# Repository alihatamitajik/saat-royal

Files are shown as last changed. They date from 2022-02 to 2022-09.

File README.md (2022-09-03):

<!-- Improved compatibility of back to top link: See: https://github.com/othneildrew/Best-README-Template/pull/73 -->

<!--
*** Thanks for checking out the Best-README-Template. If you have a suggestion
*** that would make this better, please fork the repo and create a pull request
*** or simply open an issue with the tag "enhancement".
*** Don't forget to give the project a star!
*** Thanks again! Now go create something AMAZING! :D
-->

<!-- PROJECT SHIELDS -->
<!--
*** I'm using markdown "reference style" links for readability.
*** Reference links are enclosed in brackets [ ] instead of parentheses ( ).
*** See the bottom of this document for the declaration of the reference variables
*** for contributors-url, forks-url, etc. This is an optional, concise syntax you may use.
*** https://www.markdownguide.org/basic-syntax/#reference-style-links
-->
[][contributors-url]
[][forks-url]
[][stars-url]
[][issues-url]
[][license-url]
[][linkedin-url]

<!-- PROJECT LOGO -->
<br />
<div align="center">
  <a href="https://github.com/alihatamitajik/saat-royal">
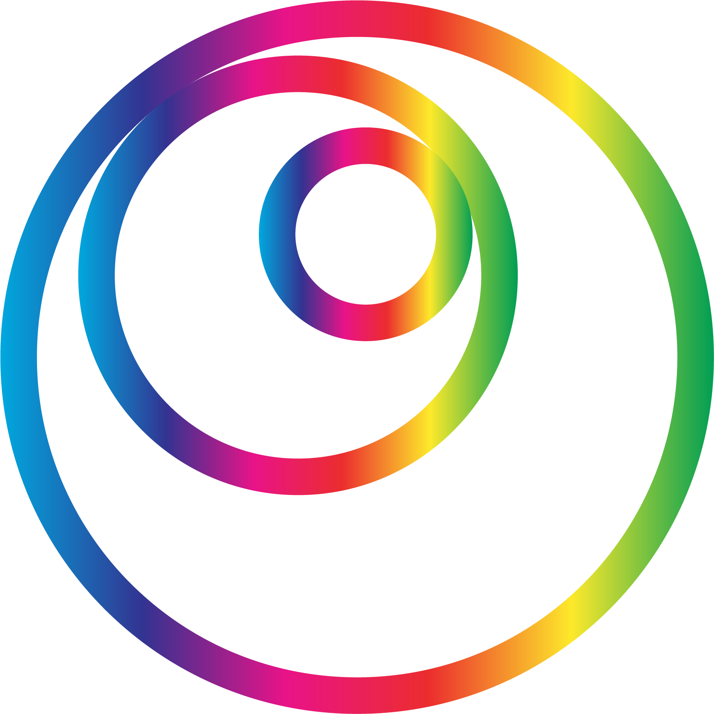
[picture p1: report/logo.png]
    
  </a>

<h3 align="center">Sa@RoyAl</h3>

  <p align="center">
    NodeMCU-based Analog-alike RGB Clock with Android Controller
    <br />
    <a href="https://github.com/alihatamitajik/saat-royal"><strong>Explore the docs »</strong></a>
    <br />
    <br />
    <a href="https://github.com/alihatamitajik/saat-royal">View Demo</a>
    ·
    <a href="https://github.com/alihatamitajik/saat-royal/issues">Report Bug</a>
    ·
    <a href="https://github.com/alihatamitajik/saat-royal/issues">Request Feature</a>
  </p>
</div>

<!-- TABLE OF CONTENTS -->
<details>
  <summary>Table of Contents</summary>
  <ol>
    <li>
      <a href="#about-the-project">About The Project</a>
      <ul>
        <li><a href="#built-with">Built With</a></li>
      </ul>
    </li>
    <li>
      <a href="#getting-started">Getting Started</a>
      <ul>
        <li><a href="#prerequisites">Prerequisites</a></li>
        <li><a href="#installation">Installation</a></li>
      </ul>
    </li>
    <li><a href="#roadmap">Roadmap</a></li>
    <li><a href="#contributing">Contributing</a></li>
    <li><a href="#license">License</a></li>
    <li><a href="#contact">Contact</a></li>
  </ol>
</details>

<!-- ABOUT THE PROJECT -->
## About The Project

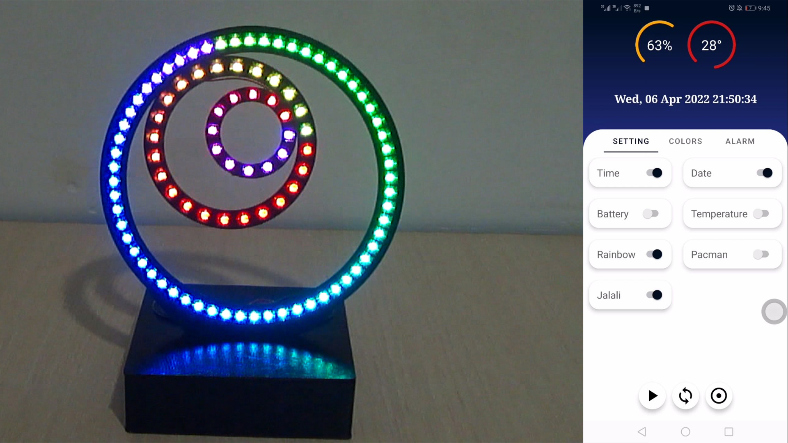
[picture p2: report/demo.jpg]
Product Name Screen Shot


This project is based on development board NodeMCU-8266 and WS2812B RGB LEDs. There are 60, 24 and 12 pieces rings in the
clock face that will represent different information and the clock settings is controlled by REST API (An android app is created
for better control). NodeMCU is on AccessPoint mode and devices must connect to its network first before they can change its
settings. 

Inspired by [This Project](https://www.instructables.com/Neopixel-Clock-With-Three-Neopixel-Rings)

Features:
* Time (Obviously! **3** Different Mode)
* Date (Jalali & Gregorian)
* Battery Percentage
* Temperature of the Room
* Two Beauty Mode (PacMan ᗤ and Rainbow 🌈)
* Alarm (Mario Theme Song)
* Customizable Colors
* REST API

<p align="right">(<a href="#readme-top">back to top</a>)</p>

### Built With

* [][Arduino-url]
* [][Android-url]
* [][VSC-url]

<p align="right">(<a href="#readme-top">back to top</a>)</p>

<!-- GETTING STARTED -->
## Getting Started

These parts is used:
* NodeMCU ESP8266 CP2102
* NeoPixel Ring - X60/X24/X12 5050 RGB LED WS2812B
* DS1307 - RTC
* Voltage Sensor
* 0.5 Watt 8 Ohm Speaker
* LM386 Mini Amplifier
* Voice Sensor FC-04
* DS18B20 - Temperature Sensor
* Printed watch face and body
* Mini Breadboard
* Jumper Wires
* 18650 Battery Shield V3 + 18650 Battery

### Prerequisites

Connect the parts to the board. Change the `#define`s relatively.

Libraries:
* ESP8266 (Board should be added to Arduino IDE ([help](https://randomnerdtutorials.com/how-to-install-esp8266-board-arduino-ide/)))
* RTClib (With this exact title)
* [ESPAsync](https://reacoda.gitbook.io/molemi-iot/introducing-the-nodemcu/display-the-dht11-sensor-reading-on-a-web-server-using-nodemcu./installing-dht-library-on-the-esp8266/i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) 
* Adafruit NeoPixel
* DallasTemperature
* OneWire

### Installation

The main program of the board can be found [HERE](code). Program the board and Enjoy! 

<p align="right">(<a href="#readme-top">back to top</a>)</p>

## RoadMap

- [ ] Adding TF card that will play a custom sound
  - [ ] TF card wiring
  - [ ] Sound transfer API

<!-- CONTRIBUTING -->
## Contributing

Contributions are what make the open source community such an amazing place to learn, inspire, and create. Any contributions you make are **greatly appreciated**.

If you have a suggestion that would make this better, please fork the repo and create a pull request. You can also simply open an issue with the tag "enhancement".
Don't forget to give the project a star! Thanks again!

1. Fork the Project
2. Create your Feature Branch (`git checkout -b feature/AmazingFeature`)
3. Commit your Changes (`git commit -m 'Add some AmazingFeature'`)
4. Push to the Branch (`git push origin feature/AmazingFeature`)
5. Open a Pull Request

<p align="right">(<a href="#readme-top">back to top</a>)</p>

<!-- LICENSE -->
## License

Distributed under the MIT License. See `LICENSE.txt` for more information.

<p align="right">(<a href="#readme-top">back to top</a>)</p>

<!-- CONTACT -->
## Contact

Your Name - [@alihatamitajik](https://twitter.com/alihatamitajik) - a [DOT] hatam008 [AT] gmail [DOT] com

Project Link: [https://github.com/alihatamitajik/saat-royal](https://github.com/alihatamitajik/saat-royal)

<p align="right">(<a href="#readme-top">back to top</a>)</p>

<!-- MARKDOWN LINKS & IMAGES -->
<!-- https://www.markdownguide.org/basic-syntax/#reference-style-links -->
[contributors-shield]: https://img.shields.io/github/contributors/alihatamitajik/saat-royal.svg?style=for-the-badge
[contributors-url]: https://github.com/alihatamitajik/saat-royal/graphs/contributors
[forks-shield]: https://img.shields.io/github/forks/alihatamitajik/saat-royal.svg?style=for-the-badge
[forks-url]: https://github.com/alihatamitajik/saat-royal/network/members
[stars-shield]: https://img.shields.io/github/stars/alihatamitajik/saat-royal.svg?style=for-the-badge
[stars-url]: https://github.com/alihatamitajik/saat-royal/stargazers
[issues-shield]: https://img.shields.io/github/issues/alihatamitajik/saat-royal.svg?style=for-the-badge
[issues-url]: https://github.com/alihatamitajik/saat-royal/issues
[license-shield]: https://img.shields.io/github/license/alihatamitajik/saat-royal.svg?style=for-the-badge
[license-url]: https://github.com/alihatamitajik/saat-royal/blob/master/LICENSE
[linkedin-shield]: https://img.shields.io/badge/-LinkedIn-black.svg?style=for-the-badge&logo=linkedin&colorB=555
[linkedin-url]: https://linkedin.com/in/ali-hatami-tajik/
[product-screenshot]: report/demo.jpg
[Arduino]: https://img.shields.io/badge/%20-Arduino-00979D?style=for-the-badge&logo=Arduino&logoColor=fff
[Arduino-url]: https://Arduino.cc
[VSC]: https://img.shields.io/badge/%20-VS%20Code-007ACC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
[VSC-url]: https://code.visualstudio.com/
[Android]: https://img.shields.io/badge/%20-Android-3DDC84?style=for-the-badge&logo=Android&logoColor=fff
[Android-url]: https://www.android.com/

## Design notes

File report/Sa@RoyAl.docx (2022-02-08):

به نام خدا

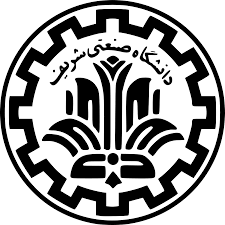
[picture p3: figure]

ساعت دیجیتال عقربه ای

پروژه درس سیستم های نهفته
جناب آقای دکتر انصاری

سارا آذرنوش 98170668

علی حاتمی 98101385

رویا قوامی 98171031

زمستان ۱۴۰۰

## مقدمه

در این پروژه یک ساعت عقربه ای با استفاده از امکانات دیجیتال بصورتی که تمام بخش های این ساعت (عقربه ها و محیط دایره ساعت) از 3 حلقه ی LED RGB ساخته شده است و با استفاده از یک اپلیکیشن موبایل میتوان بصورت بی سیم رنگ و همچنین تنظیمات زمان ساعت این ساعت را تغییر داد.

## طرح ساعت

طراحی مد نظر به این صورت است که نمایش زمان با استفاده از سه حلقه از LED های RGB با اندازه‌های ۶۰، ۲۴ و ۱۲ صورت خواهد گرفت. این حلقه ها بر روی یک پایه که حاوی ماژول های مورد نیاز ساعت است قرار میگیرد.

شکل صفحه ساعت (Watch Face) به صورت زیر است:

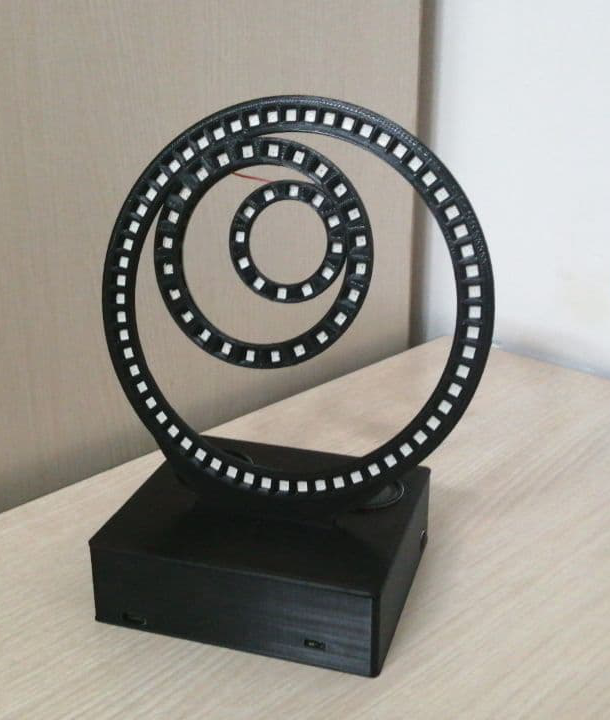
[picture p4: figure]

## لوازم مورد نیاز

لوازم مورد نیاز با توجه به ناحیه مصرف آنها عبارت‌اند از:

- پردازشی:

Cp2102 با چیپ EPS8266 بر پایه‌ی NodeMCU

- روشنایی:

برای روشنایی این ساعت از led های WS2812B پکیج 5050 استفاده خواهد شد. پیشتر استفاده از این تکنولوژی برای کنترل کردن led ها به خصوص در تعداد بالا شبیه به یک کابوس بود اما با استفاده از این led های آدرس پذیر با اتصال آنها به صورت daisy chain و تنها با استفاده از یک خط داده میتوان آنها را کنترل کرد. برای این ساعت از ۹۶ عدد از آنها به شرح زیر استفاده خواهد شد:

  - NeoPixel Ring - X60 5050 RGB LED WS2812B
  - NeoPixel Ring - X24 5050 RGB LED WS2812B
  - NeoPixel Ring - X12 5050 RGB LED WS2812B
- ساعت:

Real-time Clock DS1307 with I2C Interface

- توان این ساعت از ۹۶ چراغ LED WS2812B تشکیل شده است که در حالتی که خاموش باشند ۱ میلی آمپر و در حالت روشنایی ۶۰ میلی آمپر مصرف دارند. برای کنترل مصرف این ساعت از این تکنیک (به پیشنهاد مهندس سیادت‌زاده) استفاده خواهد شد که ساعت همیشه روشن نخواهد بود و تنها در رویدادهای خاصی (مثل دریافت صدای کف‌زدن یا بر اساس یک تایمر خاص) زمان را نشان خواهد داد. برای توان بخشی از مدار از ملزومات زیر استفاده خواهد شد:

2200 - 18650 ‌Battery Shield V3:

این شیلد دارای یک، دو یا چهار باطری است که خروجی ثابت ۵ ولت و ۳ ولت به ما تحویل می‌دهد و برای روشن کردن چراغ‌ها و میکروکنترلر استفاده میشود. این شیلد کار تنظیم و مصرف توان را بسیار ساده می‌کند.

Voltage Sensor:

از یک سنسور ولتاژ برای گرفتن ولتاژ خام دو سر باتری استفاده می‌شود تا با توجه به ولتاژ آن بتوان میزان باطری باقی‌مانده درون آن را خواند و با توجه به منحنی شارژ دهی-میزان شارژ باقی‌مانده شارژ باطری را نمایش داد. البته شیلد باطری خود این کار را می کند اما چون می‌خواهیم این اطلاعات از طریق نرم‌افزار قابل دسترسی باشند به این سنسور نیاز خواهیم داشت.

- صوت: در بخش اختیاری است و می‌توان صوت‌های دلخواه را روی یک میکرو sd ریخت یا اینکه برای درایو بهتر اسپیکر از یک آمپلیفایر استفاده کرد. اما می‌توان تنها به اسپیکر اکتفا کرد و با استفاده از تن‌ها، موسیقی‌های ابتدایی برای زنگ و دیگر کارکرد‌ها ساخت.
  - 0.5 Watt 8 Ohm Speaker
  - (Optional) LM386 Mini Amplifier
  - (Optional) Micro SD Card Module
- سنسورها:
  - Voice Sensor FC-04
  - TTP223 Touch Sensor
  - DS18B20 Temperature Sensor
- ملزومات ساخت:
  - Printed watch face and body
  - Mini Breadboard
  - Jumper Wires
  - Soldering iron + ...

## قابلیت‌ها

- نمایش ساعت (با چند نحوه نمایش متفاوت)
- دارای mode هایی برای استفاده به عنوان چراغ خواب یا تزئین
- قابلیت کنترل و تغییر برنامه و اطلاع از وضعیت فعلی توسط اپلیکیشن موبایل
- هشدار (آلارم)
- حالات متفاوت رنگ
- نمایش تاریخ
- نمایش دما

## مراحل کار

### نوشتن پروپوزال:

نیازمندی‌ها و هدف از انجام پروژه را مشخص کرده و به صورت کتبی در می‌آوریم.

اسلاید (https://docs.google.com/presentation/d/1GC8DirnFEurxau7_LiZFlntKh-j90mExHD0EmSQnUcM/edit) تهیه شده و پروپوزال گیت هاب (https://github.com/Sharif-Embedded-system/final_project-azarnoosh-hatamitajik-ghavami/tree/main/proposal) در این لینک‌‌ها موجود هستند.

### تهیه قطعات مورد نیاز:

در ابتدا با توجه به نیازمندی های پروژه، قطعات مورد نیاز گفته شده را تهیه میکنیم.

### ساخت قالب موردنظر:

برای ساخت به قالب فیزیکی ساعت به دو بخش زیر نیاز داریم.

ساعت:

سه حلقه 60، 24 و 12 عددی که به ترتیب اندازه به شکل مماس در شمال غربی حلقه 60 عددی قرار میگرند و ابعاد آن متناسب با رشته LED تهیه شده است.

پایه:

یک مکعب مستطیل خالی که ماژول های مورد نیاز گفته شده در داخل آن قرار میگیرند و ساعت روی آن قرار میگرد.

نتیجه نهایی در گیت هاب (https://github.com/Sharif-Embedded-system/final_project-azarnoosh-hatamitajik-ghavami/tree/main/report/3d-model) موجود است.

### ساخت فیزیکی و انجام اتصال فیزیکی:

ریسه‌های LEDرا در حلقه مورد نظر قرار داده و میچسبانیم سپس آن ها را به صورت سریالی به یکدیگر لحیم میکنیم. ماژول های داخل نیز که شامل باتری و سنسور ولتاژ متصل به آن، ماژول ساعت و صدا هستند را همگی را به بلوتوث متصل میکنیم.

### نوشتن برنامه‌ی سخت افزار:

برای نوشتن کدهای سخت افزاری از Arduino و زبان c++ استفاده شده است.

* کار با میکروفون(MIC):

شکل ظاهری سخت افزار:

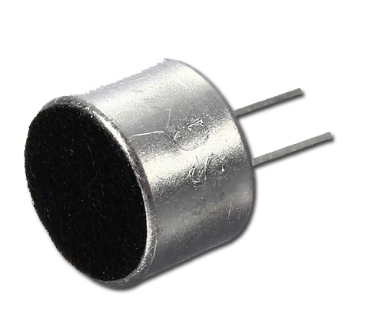
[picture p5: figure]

تابع checkTrigger: این تابع برای کار با میکروفون است که دو flag دریافت می کند و داخل loop صدا می شود و دارای دو state است:

1. "دست زدن اول" (first clap) شناسایی یا capture نشده باشد .

2. "دست زدن اول" شناسایی شده باشد و منتظر "دست زدن دوم" می ماند و اگر رخ نداد، اولی را نیز حذف می کند.

درواقع بعد از گذشتن زمانی ما بین ۳۵۰ تا ۱۳۰۰ میلی ثانیه اگر "دست زدن دوم" تشخیص داده شد، به عنوان double clap درنظر گرفته می شود و در غیر این صورت، "دست زدن اول" ی حذف می شود و دوباره مراحل داخل لوپ تکرار میشوند.

- کار با اسپیکر:

در این پروژه با اتصال یک اسپیکر به پین (pin) یازدهم (می توان پین جدید انتخاب کرد) میتوان آهنگ Super Mario Bros - Overworld theme را پخش کرد. فایل مربوطه به کدهای این قسمت در این لینک (https://github.com/Sharif-Embedded-system/final_project-azarnoosh-hatamitajik-ghavami/blob/main/code/SaRoyAl/Melody.ino) قابل مشاهده است.

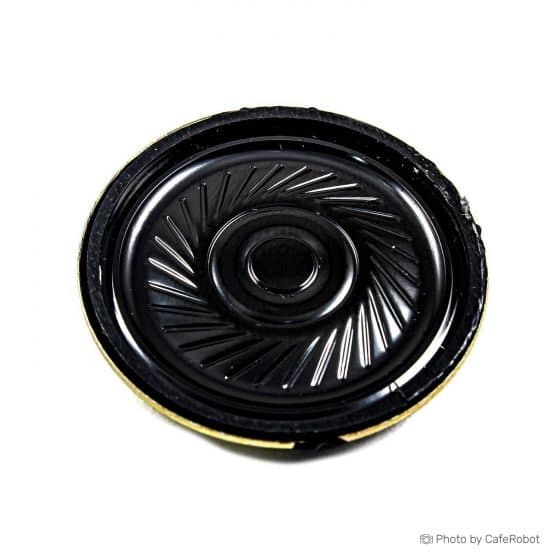
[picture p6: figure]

در این پروژه با اتصال یک زنگ پیزو به پین (pin) یازدهم (می توان پین جدید انتخاب کرد) میتوان آهنگ Super Mario Bros - Overworld theme را پخش کرد. فایل مربوطه به کدهای این قسمت در این لینک (https://github.com/Sharif-Embedded-system/final_project-azarnoosh-hatamitajik-ghavami/blob/main/code/SaRoyAl/Melody.ino) قابل مشاهده است.

کار با LED های ساعت و مودهای مختلف آن:

در این بخش، برای کنترل پیکسل ها و نوارهای LED مبتنی بر تک-سیم (single wire) از کتابخانه آردوینو (Ardunio library) استفاده شده است. این کتابخانه با تمام معماری ها سازگار بوده و بنابراین می توان از آن در تمام بردهای آردوینو استفاده کرد.

در این معماری، از سه حلقه LED با اندازه های ۶۰، ۲۴ و ۱۲ استفاده شده است و در نتیجه برای مپ کردن عدد پیکسل گفته شده به هر یک، map60، map24 و map12 را تعریف می کنیم.

ساعت دارای سه استیت کلی FF_MODE، SWING_MODE و SIMPLE_MODE برای نمایش زمان می باشد. در فایل کدهای مربوط به این قسمت (RGB.ino) به کمک توابع تعریف شده در کتابخوانه آردوینو، مانند setPixelColor و مپ های تعریف شده که بالا به آن اشاره کردیم، بعد از گرفتن زمان حال حاضر و استفاده از لیست colorScheme که در آن ۱۲ رنگ تعریف کردیم، mode های مختلف ساعت را می توان با روشن و خاموش کردن پیکسل ها نمایش داد.

- کار با RTC (Real Time Clock):

برای کار با RTC از کتابخانه RTClib استفاده می کنیم. این کتابخانه به آردوینو اجازه می دهد تا RTC داخلی (Real Time Clock) را کنترل و استفاده کند. ساعت بلادرنگ ساعتی است که زمان حال حاضر را ردیابی می کند و می توان از آن برای برنامه ریزی اقدامات برنامه در یک زمان خاص استفاده کرد.

به علاوه، RTC می تواند در هر حالت sleep mode به کار خود ادامه دهد، بنابراین، می توان از آن برای اصطلاحا "بیدار کردن " دستگاه از حالت های خواب استفاده کرد. هر بار که برد روشن می شود، RTC ریست می شود و از یک تاریخ استاندارد شروع به کار می کند.

در فایل مربوط به این قسمت (RTC.ino)، تابعی برای تشخیص آلارم (isAlarm)، تابعی برای به روزرسانی زمان (به کمک تابع rtc.now())، تابعی برای ست کردن RTC به تاریخ و زمان صریح به صورت زیر و در نهایت نیز تابع initializer آن قرار دارند.

January 21, 2014 at 3am rtc.adjust(DateTime(2014, 1, 21, 3, 0, 0))

- کار با سنسور دما:

کد مربوط به این قسمت در Temprature.ino قرار دارد. برای کار با سنسور دما، از کتابخانه های DallasTemperature.h و OneWire استفاده می کنیم. ابتدا یک instance از OneWire ساخته تا بتوان با هر وسیله ای که با یک wire می تواند وصل شود ارتباط برقرار کرد و سپس آن را به کتابخانه DallasTemperature.h می دهیم. در نهایت، به کمک تابع getTemprature، دمای محیط را به سیلسیوس بر میگردانیم.

ارتباط با اپ موبایل:

در فایل SaRoyAl.ino، کد بدنه ساعت دیجیتال قرار دارد که به توضیح آن می پردازیم:

· ریکوست هایی که می توان به ساعت فرستاد:

/ : برای تست ارتباط مناسب

status/: پاسخ این ریکواست، درصد باتری، دمای محیط و زمان فعلی است.

adjust/: با فرستادن این ریکواست، ساعت دیجیتال با ساعت محلی موبایل تنظیم می شود.

alarm/: با فرستادن این ریکواست، تنظیمات آلارم برای موبایل فرستاده می شود.

setting/: با فرستادن این ریکواست، تنظیمات استیت ها برای موبایل فرستاده می شوند.

colors/: با فرستادن این ریکواست، تنظیمات رنگ برای گوشی فرستاده می شود.

post/: با فرستادن این ریکواست، تنظیمات مورد نظر کاربر از گوشی برای میکرو ارسال می شود.

· با استفاده از کتابخانه ESPAsyncServer، یک سرور (تقریبا) آسنکرون ساخته و روی ریکواست های بالا set شده است.

· استیت های پیاده سازی شده در سیستم نیز به شرح زیر است:

1. ساعت (دارای سه مدل نمایش)
2. نشان دادن تاریخ (جلالی و میلادی)
3. نشان‌دادن درصد باطری (با استفاده از خواندن ولتاژ و مپ کردن به منحنی که شرکت سازنده ارائه کرده)
4. نشان دادن دما (با استفاده از سنسور دمای ds18b20)
5. دو مود زیبایی رنگین‌کمان و پک‌من

تمامی استیت های بالا قابلیت تنظیم دارند که نشان داده شوند یا خیر. علاوه بر این، رنگ استیت های ۱ و ۲ که مربوط به نمایش ساعت و نمایش تاریخ می باشند قابل تنظیم است. رنگ استیت های ۳ و ۴ نیز متناسب با وضعیتشان انتخاب می شود (به طور مثال اگر باطری ساعت کم باشد رنگ قرمز اگر کامل باشد رنگ آبی و مابین آن رنگ زرد اختصاص داده می شود و رنگ دما نیز متناسب با دما از رنگ قرمز برای دمای ۶۰ درجه سیلسیوس تا رنگ بنفش برای دمای ۲۰- درجه سیلسیوس تنظیم می شود).

- روند اجرا

ساعت زمانی نشان داده می شود که user دوبار دست بزند. درواقع زمانی که ساعت خاموش است و trigger نشده است، در basic state عه IDLE هستیم که منتظر capture کردن "دوبار دست زدن" است که بالاتر توصیح دادیم. سپس زمانی که trigger شد، ساعت شروع به operate میکند و داخل و از IDLEخارج می شویم. سپس به کمک تابع handleStates()، استیت های مختلف کنترل و هندل می شوند و زمانی که کار آن تمام شد، کنترلر استیت بعدی را مشخص می کند.

### ساخت برنامه‌ی موبایل:

برای کار با ساعت دیجیتال و فرستادن ریکواست به آن، یک اپ اندروید برای موبایل طراحی شد که با وصل شدن به سرور، کاربر بتواند به طور بصری، از فیچرهای پیاده سازی شده استفاده کند. این اپ شامل :

- دو فیلد برای گرفتن عدد آلارم
- یک قسمت برای انتخاب رنگ و حالت ساعت (یکی از سه حالت نمایش دادن) که شامل چهار فیلد رنگ است
- دو دراپ داون برای انتخاب حالت
- دو فیلد عددی برای آلارم
- هفت سوئیچ می باشد

که همانطور که بالاتر گفته شد، زمانی که کاربر از فیلدهای گفته شده استفاده می کند، عملیات مربوطه به صورت ریکواست به سروری فرستاده می شود که ساعت به آن وصل است و سپس بعد از دریافت ریکواست، پاسخ مناسب به آن انجام می شود.

### ارتباط و تست:

اپلیکیشن ساخته شده را به ساعت اتصال داده و ویژگی‌های خواسته شده را برای اطمینان از صحت عملکرد تست میکنیم.

## چالش‌ها:

فیزیکی:

- سایز مدل درنظر گرفته شده برای رشته ی LED ها مناسب نبود و از ابتدا قالب را طراح

کردیم.

- به علت ظریف بودن حلقه ها، اتصال و لحیم کاری آن دشوار بود و همچنین سیم در پشت آن مشخص میشد بنابراین برای تمیزکاری بیشتر نزدیکترین ها را به یکدیگر متصل کردیم که موجب پشت هم نبودن شماره‌ی LED ها میشد که آدرس دادن در کد را دشوارتر میکرد بنابراین برای راحتی کار شماره‌ی LED ها را در تابع ها برای سادگی مپ کردیم تا شماره های مناسب را خروجی دهد.

اپلیکیشن اندروید:

- در ابتدا از کتابخانه ی RemoteXY استفاده میکردیم که در اواسط کار دچار مشکل شد و مجبور شدیم از پایه بنویسیم.
- برای ساعت REST API نوشته شده است تا انعطاف بالایی سمت کاربر داشته باشد.

## نتیجه

ویدو (https://drive.google.com/drive/folders/1iEG6MFme1rayJ8v2ZiLR0NX5621aQJto?usp=sharing) از ساعت ساخته شده.

ساعت پیاده سازی شده:

مود اول ساعت:

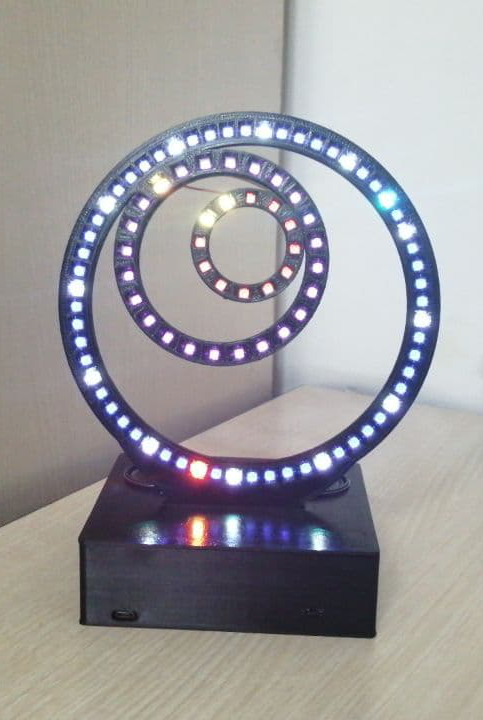
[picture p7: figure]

مود دوم ساعت:

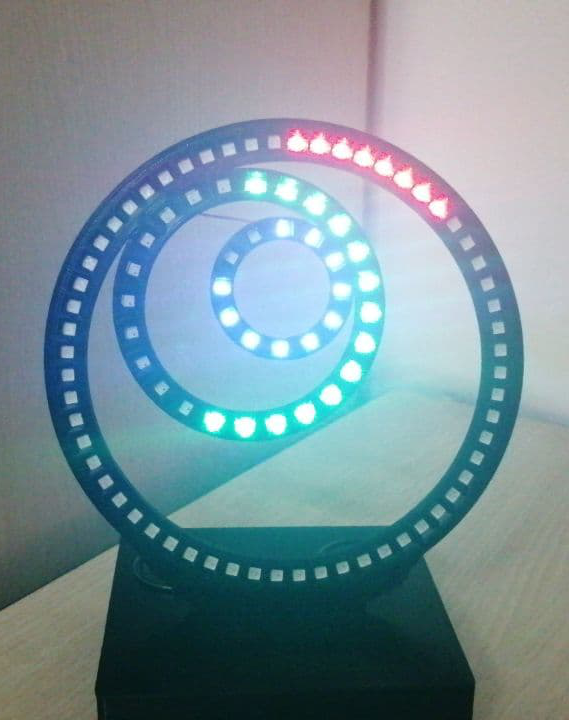
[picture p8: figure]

تاریخ جلالی

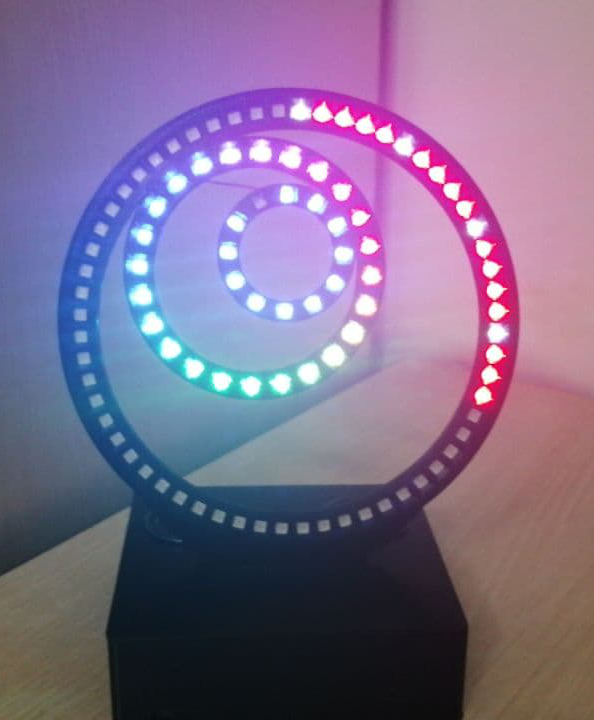
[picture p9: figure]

دما

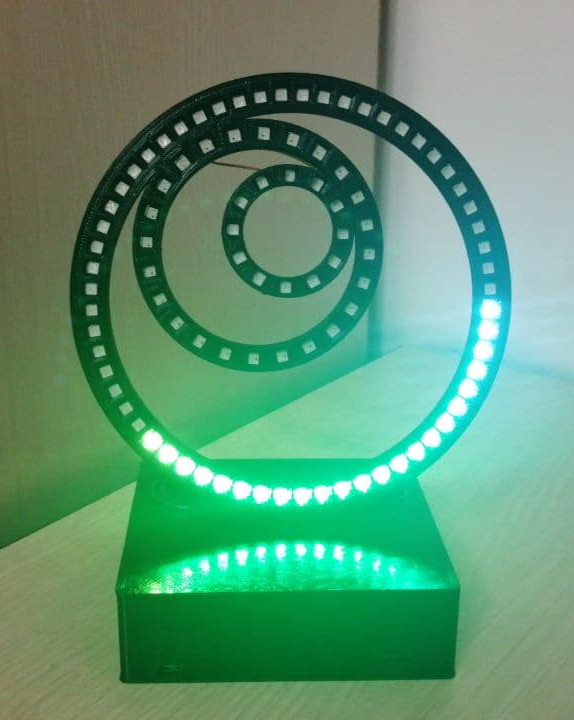
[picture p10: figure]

باتری

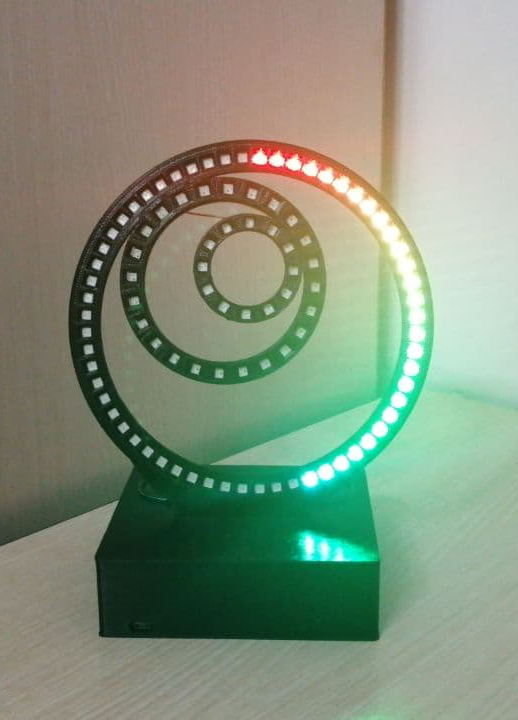
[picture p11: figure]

پکمن

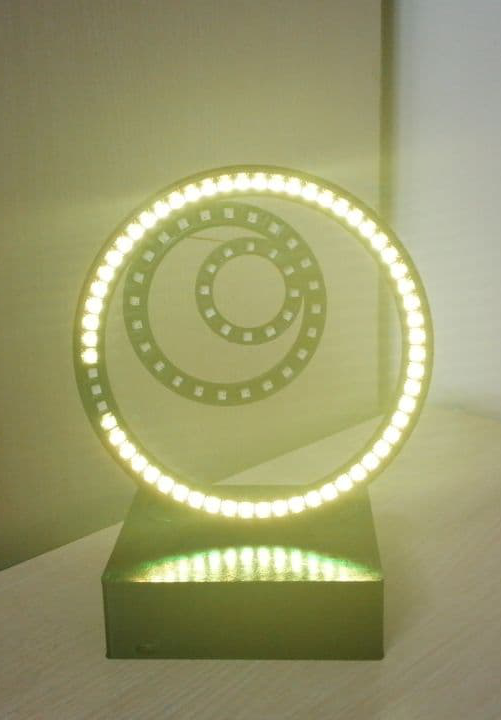
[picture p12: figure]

اپلیکیشن موبایل

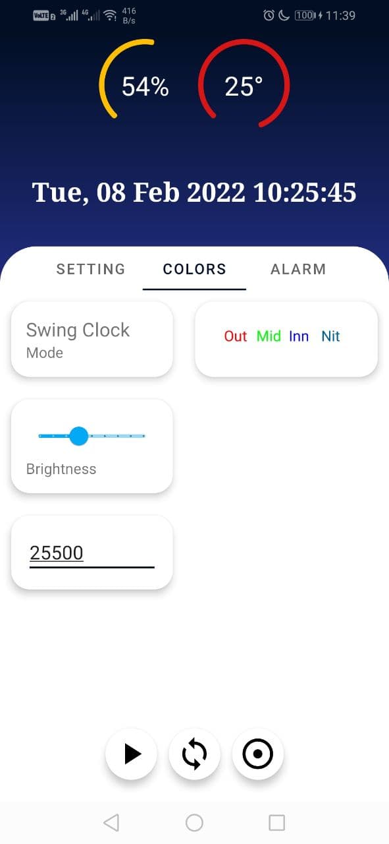
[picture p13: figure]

محل شارژ

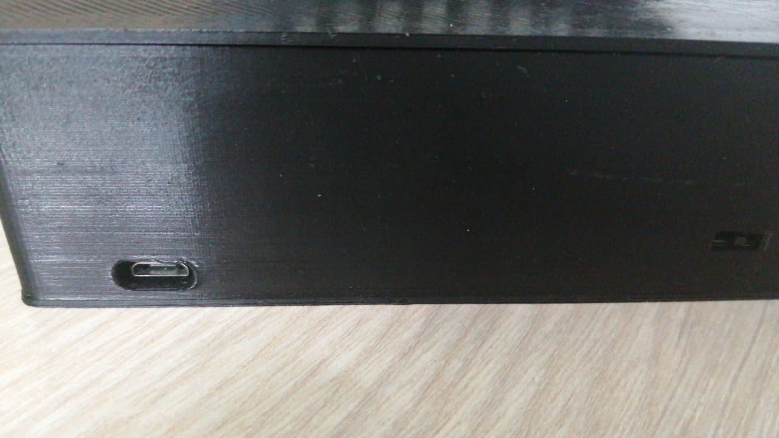
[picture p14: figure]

اسپیکر و میکروفون

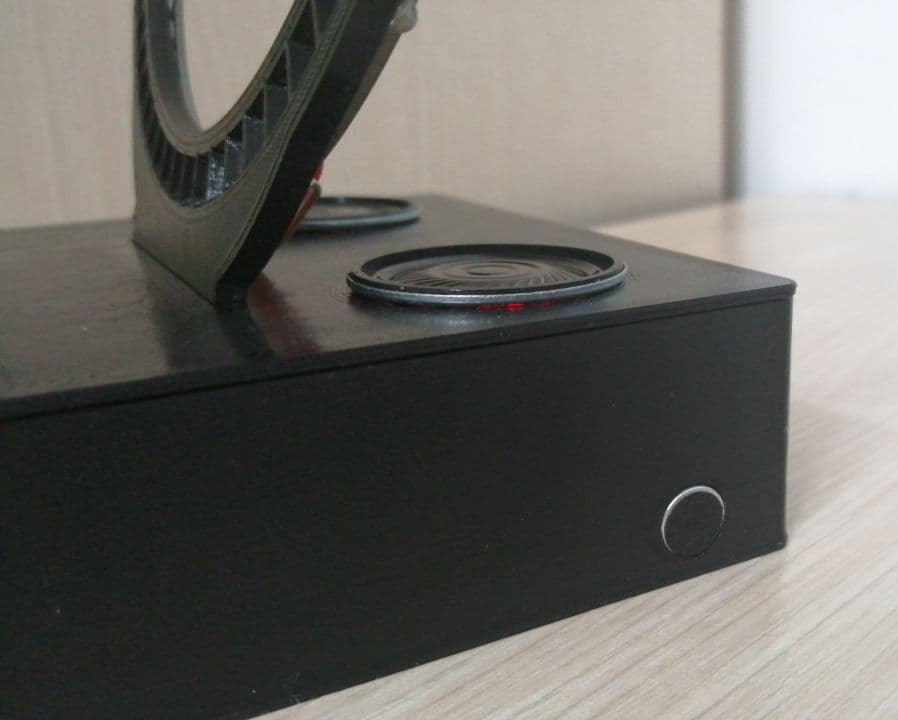
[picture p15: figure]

## منابع

1. https://www.instructables.com/Neopixel-Clock-With-Three-Neopixel-Rings/
2. https://www.youtube.com/watch?v=AR_XrYeBeIU&ab_channel=KieranGleeson
3. https://learn.adafruit.com/neopixel-ring-clock/code-and-clock-faces
4. https://github.com/milesburton/Arduino-Temperature-Control-Library
5. https://www.arduino.cc/en/Reference/RTC
6. https://github.com/me-no-dev/ESPAsyncWebServer
7. https://www.amazon.com/piezo-buzzer/s?k=piezo+buzzer
8. https://adafruit.github.io/RTClib/html/index.html

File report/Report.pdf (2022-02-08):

## به نام خدا

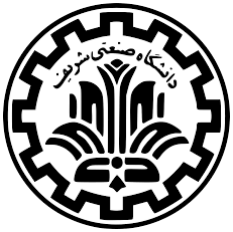
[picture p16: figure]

## ساعت دیجیتال عقربه ای

### پروژه درس سیستم های نهفته جناب آقای دکتر انصاری

سارا آذرنوش 98170668

علی حاتمی 98101385

رویا قوامی 98171031

زمستان 1۴00

فهرست

ساخت برنامه ی موبایل: 12 |
ارتباط و تست: 13 |
چالش ها13 | :
نتیجه 1۴ |
منابع 21 |

### مقدمه

در این پروژه یک ساعت عقربه ای با استفاده از امکانات دیجیتال بصورتی که تمام بخش های این ساعت )عقربه ها و محیط دایره ساعت( از 3 حلقه ی LED RGB ساخته شده است و با استفاده از یک اپلیکیشن موبایل میتوان بصورت بی سیم رنگ و همچنین تنظیمات زمان ساعت این ساعت را تغییر داد.

### طرح ساعت

طراحی مد نظر به این صورت است که نمایش زمان با استفاده از سه حلقه از LED های RGB با اندازه های ،60 2۴ و 12 صورت خواهد گرفت. این حلقه ها بر روی یک پایه که حاوی ماژول های مورد نیاز ساعت است قرار میگیرد.

شکل صفحه ساعت (Face Watch (به صورت زیر است:

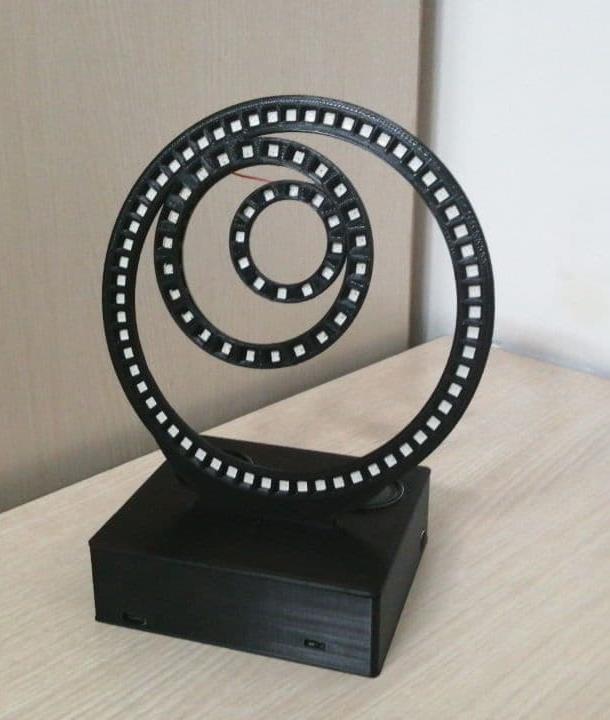
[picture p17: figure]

### لوازم مورد نیاز

لوازم مورد نیاز با توجه به ناحیه مصرف آنها عبارت اند از:
- پردازشی :

2102Cp با چیپ 8266EPS بر پایه ی NodeMCU
- روشنایی :
برای روشنایی این ساعت از led های B2812WS پکیج 5050 استفاده خواهد شد. پیشتر استفاده از این تکنولوژی برای کنترل کردن led ها به خصوص در تعداد باال شبیه به یک کابوس بود اما با استفاده از این led های آدرس پذیر با اتصال آنها به صورت chain daisy و تنها با استفاده از یک خط داده میتوان آنها را کنترل کرد. برای این ساعت از 96 عدد از آنها به شرح زیر استفاده خواهد شد :
- NeoPixel Ring - X60 5050 RGB LED WS2812B
- NeoPixel Ring - X24 5050 RGB LED WS2812B
- NeoPixel Ring - X12 5050 RGB LED WS2812B
- ساعت:

Real-time Clock DS1307 with I2C Interface
- توان
این ساعت از 96 چراغ B2812WS LED تشکیل شده است که در حالتی که خاموش باشند 1 میلی آمپر و در حالت روشنایی 60 میلی آمپر مصرف دارند. برای کنترل مصرف این ساعت از این تکنیک )به پیشنهاد مهندس سیادتزاده( استفاده خواهد شد که ساعت همیشه روشن نخواهد بود و تنها در رویدادهای خاصی )مثل دریافت صدای کف زدن یا بر اساس یک تایمر خاص( زمان را نشان خواهد داد. برای توان بخشی از مدار از ملزومات زیر استفاده خواهد شد :

2200 - 18650 Battery Shield V3:
این شیلد دارای یک، دو یا چهار باطری است که خروجی ثابت 5 ولت و 3 ولت به ما تحویل می دهد و برای روشن کردن چراغ ها و میکروکنترلر استفاده میشود. این شیلد کار تنظیم و مصرف توان را بسیار ساده می کند .

Voltage Sensor:

از یک سنسور ولتاژ برای گرفتن ولتاژ خام دو سر باتری استفاده می شود تا با توجه به ولتاژ آن بتوان میزان باطری باقی مانده درون آن را خواند و با توجه به منحنی شارژ دهی- میزان شارژ باقیمانده شارژ باطری را نمایش داد. البته شیلد باطری خود این کار را می کند اما چون می خواهیم این اطالعات از طریق نرم افزار قابل دسترسی باشند به این سنسور نیاز خواهیم داشت.

- صوت :
در بخش اختیاری است و میتوان صوت های دلخواه را روی یک میکرو sd ریخت یا اینکه برای درایو بهتر اسپیکر از یک آمپلیفایر استفاده کرد. اما می توان تنها به اسپیکر اکتفا کرد و با استفاده از تنها، موسیقی های ابتدایی برای زنگ و دیگر کارکرد ها ساخت.
- 0.5 Watt 8 Ohm Speaker
- (Optional) LM386 Mini Amplifier
- (Optional) Micro SD Card Module
- سنسورها:
- Voice Sensor FC-04
- TTP223 Touch Sensor
- DS18B20 Temperature Sensor
- ملزومات ساخت:
- Printed watch face and body
- Mini Breadboard
- Jumper Wires
- Soldering iron + ...

### قابلیتها

- نمایش ساعت )با چند نحوه نمایش متفاوت(
- دارای mode هایی برای استفاده به عنوان چراغ خواب یا تزئین
- قابلیت کنترل و تغییر برنامه و اطالع از وضعیت فعلی توسط اپلیکیشن موبایل
- هشدار )آالرم(
- حاالت متفاوت رنگ
- نمایش تاریخ
- نمایش دما

### مراحل کار نوشتن پروپوزال:

نیازمندیها و هدف از انجام پروژه را مشخص کرده و به صورت کتبی در می آوریم. اسالید (https://docs.google.com/presentation/d/1GC8DirnFEurxau7_LiZFlntKh-j90mExHD0EmSQnUcM/edit) تهیه شده و پروپوزال گیت ها (https://github.com/Sharif-Embedded-system/final_project-azarnoosh-hatamitajik-ghavami/tree/main/proposal)ب (https://github.com/Sharif-Embedded-system/final_project-azarnoosh-hatamitajik-ghavami/tree/main/proposal) در این لینک ها موجود هستند.

### تهیه قطعات مورد نیاز:

در ابتدا با توجه به نیازمندی های پروژه، قطعات مورد نیاز گفته شده را تهیه میکنیم.

### ساخت قالب موردنظر:

برای ساخت به قالب فیزیکی ساعت به دو بخش زیر نیاز داریم. ساعت:
سه حلقه ،60 2۴ و 12 عددی که به ترتیب اند ازه به شکل مماس در شمال غربی حلقه 60 عددی قرار میگرند و ابعاد آن متناسب با رشته LED تهیه شده است. پایه:
یک مکعب مستطیل خالی که ماژول های مورد نیاز گفته شده در داخل آن قرار میگیرند و ساعت روی آن قرار میگرد.
نتیجه نهایی در گیت هاب (https://github.com/Sharif-Embedded-system/final_project-azarnoosh-hatamitajik-ghavami/tree/main/report/3d-model) موجود است.

### ساخت فیزیکی و انجام اتصال فیزیکی:

ریسه های LEDرا در حلقه مورد نظر قرار داده و میچسبانیم سپس آن ها را به صورت سریالی به یکدیگر لحیم میکنیم. ماژول های داخل نیز که شامل باتری و سنسور ولتاژ متصل به آن، ماژول ساعت و صدا هستند را همگی را به بلوتوث متصل میکنیم .

### نوشتن برنامهی سخت افزار:

برای نوشتن کدهای سخت افزاری از Arduino و زبان ++c استفاده شده است. * کار با میکروفون)MIC):
شکل ظاهری سخت افزار:

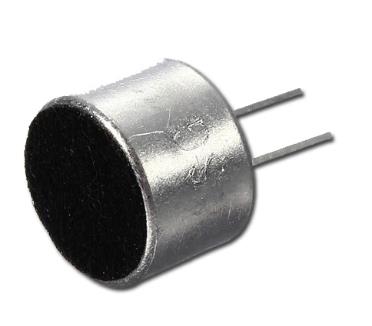
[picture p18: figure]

تابع checkTrigger: این تابع برای کار با میکروفون است که دو flag دریافت می کند و داخل loop صدا می شود و دارای دو state است: .1 "دست زدن اول" )clap first )شناسایی یا capture نشده باشد . .2 "دست زدن اول" شناسایی شده باشد و منتظر "دست زدن دوم" می ماند و اگر رخ نداد، اولی را نیز حذف می کند .
درواقع بعد از گذشتن زمانی ما بین 350 تا 1300 میلی ثانیه اگر "دست زدن دوم" تشخیص داده شد، به عنوان clap double درنظر گرفته می شود و در غیر این صورت، "دست زدن اول" ی حذف می شود و دوباره مراحل داخل لوپ تکرار میشوند.
- کار با اسپیکر:
در این پروژه با اتصال یک اسپیکر به پین ) pin )یازدهم )می توان پین جدید انتخاب کرد( میتوان آهنگ theme Overworld - Bros Mario Super را پخش کرد. فایل مربوطه به کدهای این قسمت در این ل (https://github.com/Sharif-Embedded-system/final_project-azarnoosh-hatamitajik-ghavami/blob/main/code/SaRoyAl/Melody.ino)ینک (https://github.com/Sharif-Embedded-system/final_project-azarnoosh-hatamitajik-ghavami/blob/main/code/SaRoyAl/Melody.ino) قابل مشاهده است.

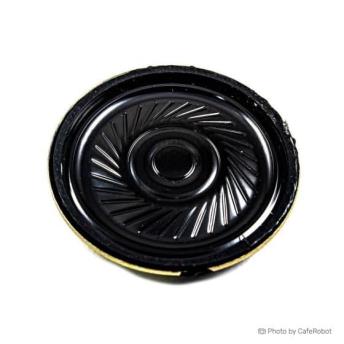
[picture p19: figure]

در این پروژه با اتصال یک زنگ پیزو به پین ) pin )یازدهم )می توان پین جدید انتخاب کرد( میتوان آهنگ theme Overworld - Bros Mario Super را پخش کرد. فایل مربوطه به کدهای این قسمت در این ل (https://github.com/Sharif-Embedded-system/final_project-azarnoosh-hatamitajik-ghavami/blob/main/code/SaRoyAl/Melody.ino)ینک (https://github.com/Sharif-Embedded-system/final_project-azarnoosh-hatamitajik-ghavami/blob/main/code/SaRoyAl/Melody.ino) قابل مشاهده است.

کار با LED های ساعت و مودهای مختلف آن:

در این بخش، برای کنترل پیکسل ها و نوارهای LED مبتنی بر تک-سیم )wire single )از کتابخانه آردوینو ) library Ardunio )استفاده شده است. این کتابخانه با تمام معماری ها سازگار بوده و بنابراین می توان از آن در تمام بردهای آردوینو استفاده کرد. در این معماری، از سه حلقه LED با اندازه های ،60 2۴ و 12 استفاده شده است و در نتیجه برای مپ کردن عدد پیکسل گفته شده به هر یک، 60map، 24map و 12map را تعریف می کنیم. ساعت دارای سه استیت کلی MODE_FF، MODE_SWING و MODE_SIMPLE برای نمایش زمان می باشد. در فایل کدهای مربوط به این قسمت ) ino.RGB )به کمک توابع تعریف شده در کتابخوانه آردوینو، مانند setPixelColor و مپ های تعریف شده که باال به آن اشاره کردیم، بعد از گرفتن زمان حال حاضر و استفاده از لیست colorScheme که در آن 12 رنگ تعریف کردیم، mode های مختلف ساعت را می توان با روشن و خاموش کردن پیکسل ها نمایش داد.
:)Real Time Clock( RTC با کار •
برای کار با RTC از کتابخانه RTClib استفاده می کنیم. این کتابخانه به آردوینو اجازه می دهد تا RTC داخلی ) Clock Time Real )را کنترل و استفاده کند. ساعت بالدرنگ ساعتی است که زمان حال حاضر را ردیابی می کند و می توان از آن برای برنامه ریزی اقدامات برنامه در یک زمان خاص استفاده کرد.
به عالوه، RTC می تواند در هر حالت mode sleep به کار خود ادامه دهد، بنابراین، می توان از آن برای اصطالحا "بیدار کردن " دستگاه از حالت های خواب استفاده کرد. هر بار که برد روشن می شود، RTC ریست می شود و از یک تاریخ استاندارد شروع به کار می کند. در فایل مربوط به این قسمت )ino.RTC)، تابعی برای تشخیص آالرم )isAlarm)، تابعی برای به روزرسانی زمان )به کمک تابع now.rtc))(، تابعی برای ست کردن RTC به تاریخ و زمان صریح به صورت زیر و در نهایت نیز تابع initializer آن قرار دارند.
January 21, 2014 at 3am rtc.adjust(DateTime(2014, 1, 21, 3, 0, 0))
- کار با سنسور دما:
کد مربوط به این قسمت در ino.Temprature قرار دارد. برای کار با سنسور دما، از کتابخانه های
h.DallasTemperature و OneWire استفاده می کنیم. ابتدا یک instance از OneWire
ساخته تا بتوان با هر وسیله ای که با یک wire می تواند وصل شود ارتباط برقرار کرد و سپس آن را به کتابخانه h.DallasTemperature می دهیم. در نهایت، به کمک تابع getTemprature، دمای محیط را به سیلسیوس بر میگردانیم.

ارتباط با اپ موبایل:

در فایل ino.SaRoyAl، کد بدنه ساعت دیجیتال قرار دارد که به توضیح آن می پردازیم:

- ریکوست هایی که می توان به ساعت فرستاد:

/ : برای تست ارتباط مناسب

status:/ پاسخ این ریکواست، درصد باتری، دمای محیط و زمان فعلی است.

adjust:/ با فرستادن این ریکواست، ساعت دیجیتال با ساعت محلی موبایل تنظیم می شود.

alarm:/ با فرستادن این ریکواست، تنظیمات آالرم برای موبایل فرستاده می شود.

setting:/ با فرستادن این ریکواست، تنظیمات استیت ها برای موبایل فرستاده می شوند.

colors:/ با فرستادن این ریکواست، تنظیمات رنگ برای گوشی فرستاده می شود.

post:/ با فرستادن این ریکواست، تنظیمات مورد نظر کاربر از گوشی برای میکرو ارس ال می شود.

- با استفاده از کتابخانه ESPAsyncServer، یک سرور )تقریبا( آسنکرون ساخته و روی ریکواست های باال set شده است.
- استیت های پیاده سازی شده در سیستم نیز به شرح زیر است:

.1 ساعت )دارای سه مدل نمایش(

.2 نشان دادن تاریخ )جاللی و میالدی(

.3 نشاندادن درصد باطری )با استفاده از خواندن ولتاژ و مپ کردن به منحنی که شرکت سازنده ارائه کرده(

.4 نشان دادن دما )با استفاده از سنسور دمای 20b18ds )

.5 دو مود زیبایی رنگین کمان و پکمن

تمامی استیت های باال قابلیت تنظیم دارند که نشان داده شوند یا خیر. عالوه بر این، رنگ استیت های 1 و 2 که مربوط به نمایش ساعت و نمایش تاریخ می باشند قابل تنظیم است. رنگ استیت های 3 و ۴ نیز متناسب با وضعیتشان انتخاب می شود )به طور مثال اگر باطری ساعت کم باشد رنگ قرمز اگر کامل باشد رنگ آبی و مابین آن رنگ زرد اختصاص داده می شود و رنگ دما نیز متناس ب با دما از رنگ قرمز برای دمای 60 درجه سیلسیوس تا رنگ بنفش برای دمای -20 درجه سیلسیوس تنظیم می شود(.

- روند اجرا

ساعت زمانی نشان داده می شود که user دوبار دست بزند. درواقع زمانی که ساعت خاموش است و trigger نشده است، در state basic عه IDLE هستیم که منتظر capture کردن "دوبار دست زدن" است که باالتر توصیح دادیم. سپس زمانی که trigger شد، ساعت شروع به operate میکند و داخل و از IDLEخارج می شویم. سپس به کمک تابع handleStates)(، استیت های مختلف کنترل و هندل می شوند و زمانی که کار آن تمام شد، کنترلر استیت بعد ی را مشخص می کند.

### ساخت برنامهی موبایل:

برای کار با ساعت دیجیتال و فرستادن ریکواست به آن، ی ک اپ اندروید برای موبایل طراحی شد که با وصل شدن به سرور، کاربر بتواند به طور بصری، از فیچرها ی پیاده سازی شده استفاده کند. این اپ شامل:
- دو فی لد برای گرفتن عدد آالرم
- یک قسمت برا ی انتخاب رنگ و حالت ساعت )یکی از سه حالت نمایش دادن( که شامل چهار فیلد رنگ است
- دو دراپ داون برای انتخاب حالت
- دو فیلد عددی برای آالرم
- هفت سوئیچ می باشد
که همانطور که باالتر گفته شد، زمانی که کاربر از ف یلدهای گفته شده استفاده می کند، عملیات مربوطه به صورت ریکواست به سرور ی فرستاده می شود که ساعت به آن وصل است و سپس بعد از دریافت ریکواست، پاسخ مناسب به آن انجام می شود.

### ارتباط و تست:

اپلیکیشن ساخته شده را به ساعت اتصال داده و ویژگی های خواسته شده را برای اطمینان از صحت عملکرد تست میکنیم.

### چالشها:

فیزیکی:

- سایز مدل درنظر گرفته شده برای رشته ی LED ها مناسب نبود و از ابتدا قالب را طراح کردیم.
- به علت ظریف بودن حلقه ها، اتصال و لحیم کاری آن دشوار بود و همچنین سیم در پشت آن مشخص میشد بنابراین برای تمیزکاری بیشتر نزدیکترین ها را به یکدیگر متصل کردیم که موجب پشت هم نبودن شماره ی LED ها میشد که آدرس دادن در کد را دشوارتر میکرد بنابراین برای راحتی کار شماره ی LED ها را در تابع ها برای سادگی مپ کردیم تا شماره های مناسب را خروجی دهد.

اپلیکیشن اندروید:

- در ابتدا از کتابخانه ی RemoteXY است فاده میکردیم که در اواسط کار دچار مشکل شد و مجبور شدیم از پایه بنویسیم.
- برای ساعت API REST نوشته شده است تا انعطاف باالیی سمت کاربر داشته باشد.

### نتیجه

ویدو (https://drive.google.com/drive/folders/1iEG6MFme1rayJ8v2ZiLR0NX5621aQJto?usp=sharing) از ساعت ساخته شده.

ساعت پیاده سازی شده:

مود اول ساعت:

مود دوم ساعت:

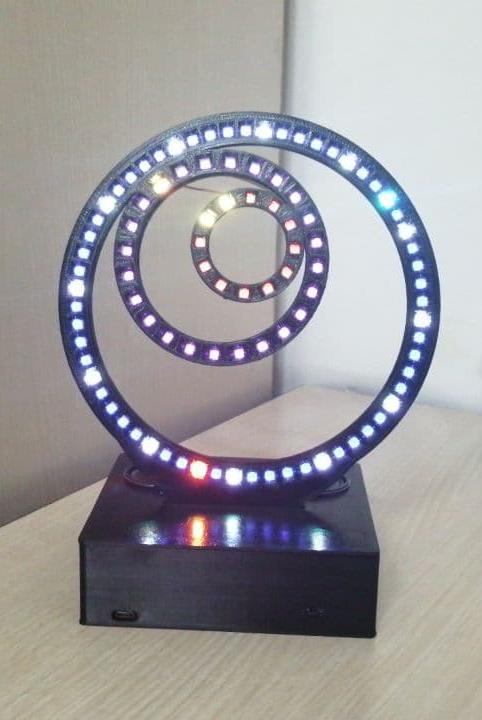
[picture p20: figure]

تاریخ جالل ی

دما

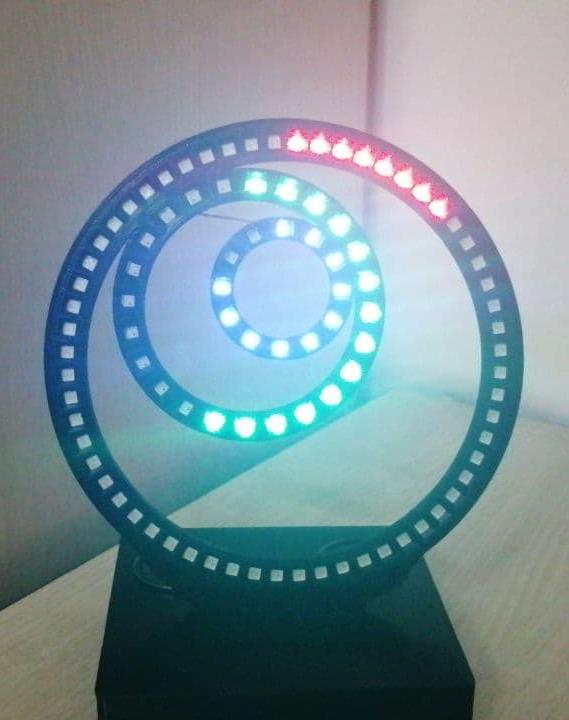
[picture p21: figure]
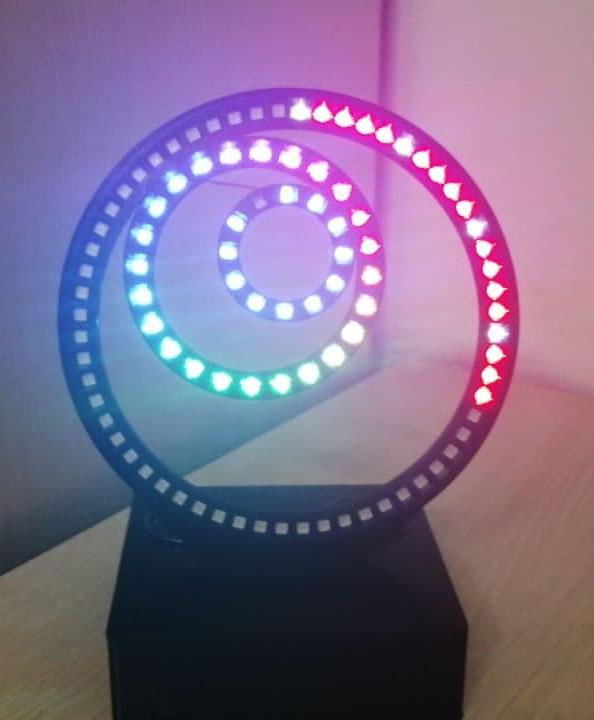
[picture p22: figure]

باتری

پکمن

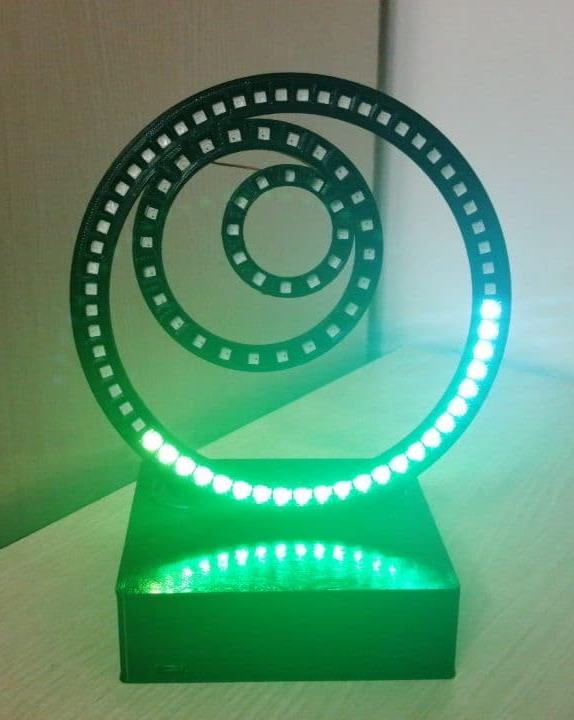
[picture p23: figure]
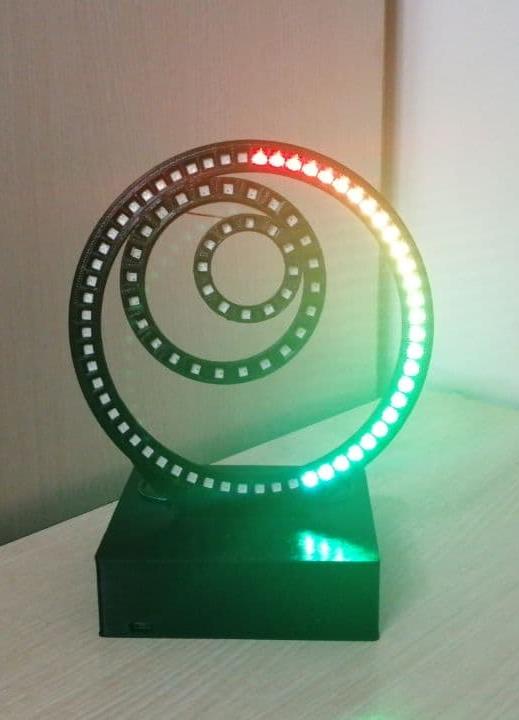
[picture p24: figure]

اپلیکیشن موبایل

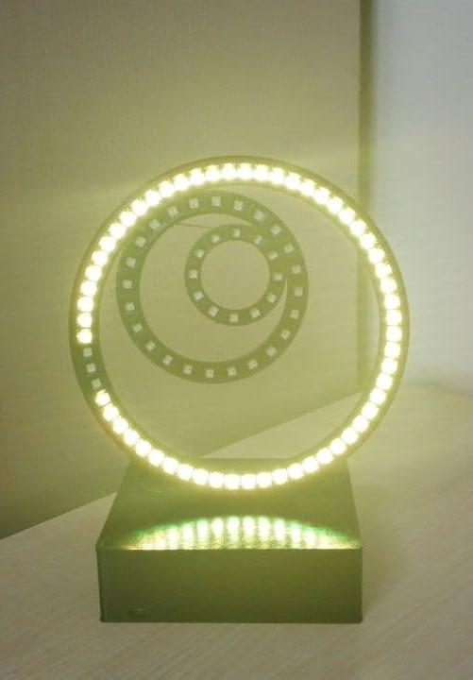
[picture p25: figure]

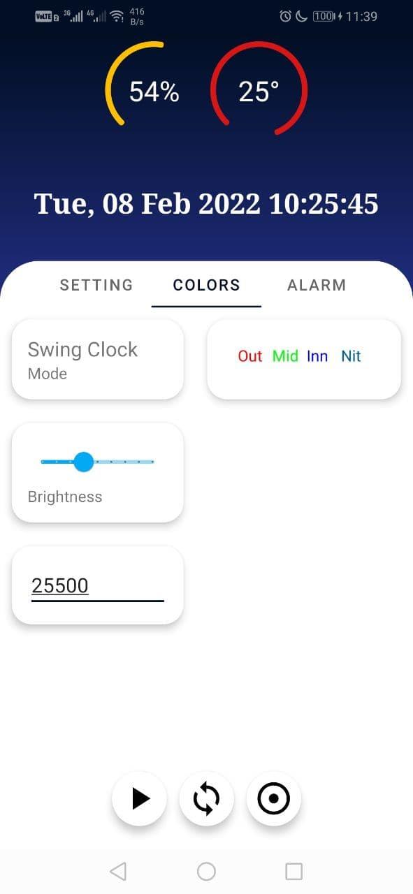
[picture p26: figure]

محل شارژ

اسپیکر و میکروفون

### منابع

1. https://www.instructables.com/Neopixel-Clock-With-Three-Neopixel-Rings /
2. https://www.youtube.com/watch?v=AR_XrYeBeIU&ab_channel=KieranGleeson
3. https://learn.adafruit.com/neopixel-ring-clock/code-and-clock-faces
4. https://github.com/milesburton/Arduino-Temperature-Control-Library
5. https://www.arduino.cc/en/Reference/RTC
6. https://github.com/me-no-dev/ESPAsyncWebServer
7. https://www.amazon.com/piezo-buzzer/s?k=piezo+buzzer
8. https://adafruit.github.io/RTClib/html/index.html

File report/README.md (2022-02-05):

# گزارش انجام پروژه درس سیستم‌های نهفته (ساعت هوشمند)

# آماده‌سازی
این فاز شامل دو مرحله کلی است:
1. خرید لوازم مورد نیاز
2. باز طراحی بدنه و کیس

از آنجایی که پس از تهیه تجهیزات به این مورد برخورد کردیم که LED های خریداری شده متناسب با طرحی که در پروپوزال ارائه شده بود (که از اینترنت گرفته شده بود) نیست، یک بدنه و کیس از ابتدا طراحی شد. فایل بدنه و کیس طراحی شده در کنار این گزارش قرار گرفته‌اند.

مدل بدنه و کیس

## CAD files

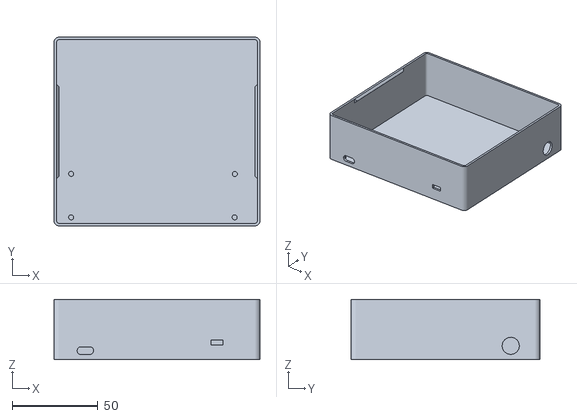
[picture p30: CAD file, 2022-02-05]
3d-model/Case.stl
120.0 x 110.0 x 35.0

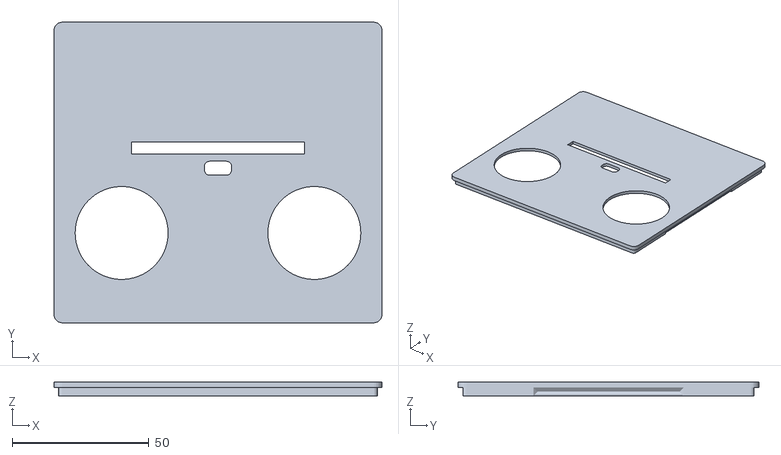
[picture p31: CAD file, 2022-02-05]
3d-model/Cover.stl
120.0 x 110.0 x 5.00

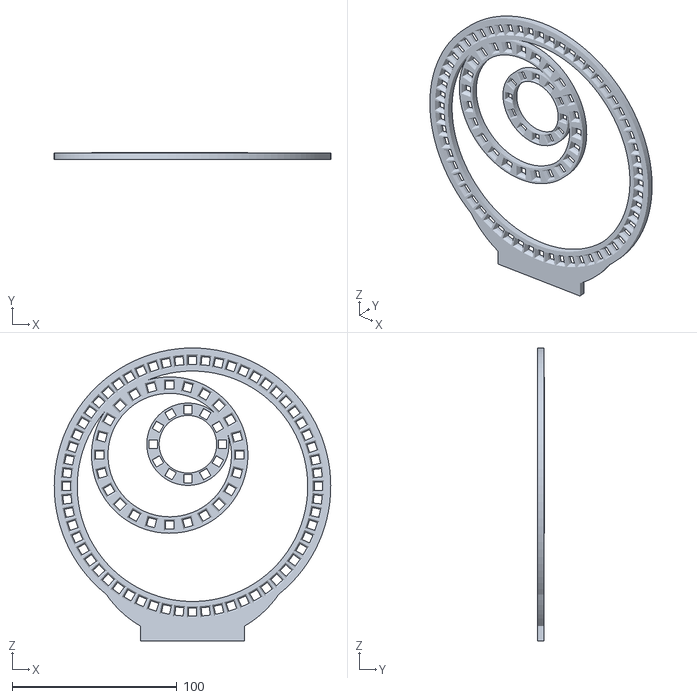
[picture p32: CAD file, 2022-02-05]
3d-model/face.stl
168.0 x 4.06 x 178.0

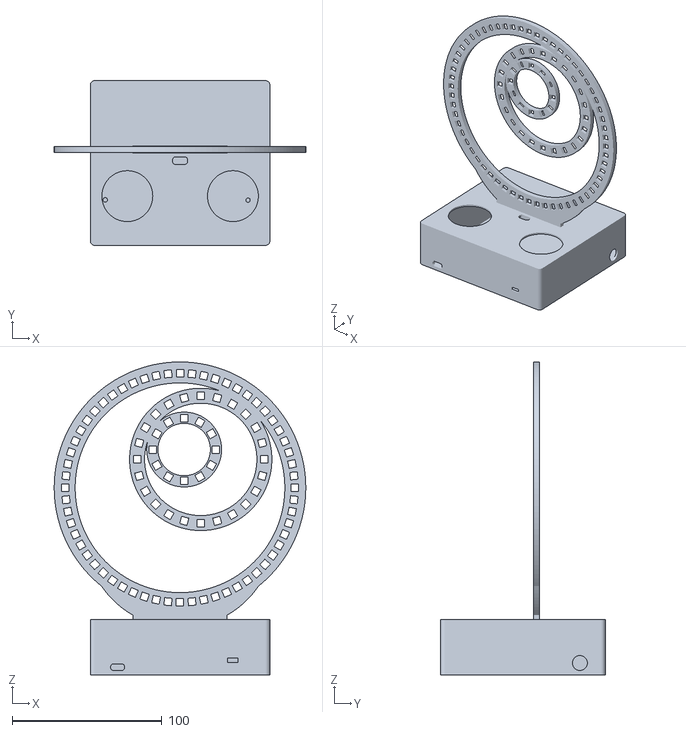
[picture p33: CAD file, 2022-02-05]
3d-model/Enclosure v7.stl
168.0 x 110.0 x 209.0

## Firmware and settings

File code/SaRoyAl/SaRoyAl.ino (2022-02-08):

/*
   -- SaRoyAl --   
*/

#include <ESP8266WiFi.h>
#include <string.h>
#include <RTClib.h>
#include <iostream>
#include <string>
#include <ESPAsyncTCP.h>
#include <ESPAsyncWebServer.h>

// Variables
// State Variables for Operate
uint8_t state = 0;
bool isOperating = false;
long lastCheckpoint;
long alarmCheck = millis();
int32_t threshold = 1000;
// Mic
bool isTriggered = false;
uint8_t batteryPercent;
int8_t temprature;

// Time
DateTime noww;

// To Be Used As Local Counters
long startState;
uint32_t i_loc;
uint32_t j;
uint32_t k;
uint8_t var1;

bool shouldLog = false;
int8_t log_temprature;
uint8_t log_battery;

// Settings
struct {
  // Alaram
  uint8_t alarmH;
  uint8_t alarmM;
  // Booleans
  uint8_t isAlarm;
  uint8_t isShowClock;
  uint8_t isShowDate;
  uint8_t isShowBattery;
  uint8_t isTemprature;
  uint8_t isShowRainbow;
  uint8_t isShowPackman;
  // Modes
  uint8_t modeClock;  // 0: FF, 1: Swing, 2: Simple
  uint8_t ffMode;
  uint32_t color60;
  uint32_t color24;
  uint32_t color12;
  uint32_t color12N;
  uint8_t  brightness;
  uint8_t isJalali;
} Prefrences ={0,0,0,1,1,1,1,1,1,2,0,16711680,65280,255,25500, 50, 0};


AsyncWebServer server(80);


const char* ssid = "ESP-SaRoyAl";          // Your WiFi SSID
const char* password = "LaYorSa-PSE";  // Your WiFi Password

void notFound(AsyncWebServerRequest *request) {
    request->send(404, "text/plain", "Not found");
}

/**
 * This function is to prepare battery percentage and temprature for
 * Status request. Prepration is time taking and cause problem for sending
 * requests so they should be prepared beforehand.
 */
void handleGetReady (AsyncWebServerRequest *request) {
  request->send(200, "text/plain", "WAIT 2000ms ...");
  shouldLog= true;
}

/**
 * Send status of the clock to the app on 192.168.4.1/status
 */
void handleGetSatus (AsyncWebServerRequest *request) {
  updateTime();
  char form[] = "DDD, DD MMM YYYY hh:mm:ss";
  String stat;
  stat += "{\"Current\":\"" +     String(noww.toString(form)) + "\",";
  stat += "\"temprature\":" +     String(log_temprature) + ",";
  stat += "\"battery\":" +        String(log_battery) + "}";
  request->send(200, "application/json", stat);
}

/**
 * send settings to switches on 192.168.4.1/setting
 */
void handleGetSetting (AsyncWebServerRequest *request) {
  String stat;
  stat += "{\"isShowClock\":" +   String(Prefrences.isShowClock) + ",";
  stat += "\"isShowDate\":" +     String(Prefrences.isShowDate) + ",";
  stat += "\"isShowBattery\":" +  String(Prefrences.isShowBattery) + ",";
  stat += "\"isTemprature\":" +   String(Prefrences.isTemprature) + ",";
  stat += "\"isShowRainbow\":" +  String(Prefrences.isShowRainbow) + ",";
  stat += "\"isShowPackman\":" +  String(Prefrences.isShowPackman) + ",";
  stat += "\"isJalali\":" +       String(Prefrences.isJalali) + "}";
  request->send(200, "application/json", stat);
}

/*
 * Alarm settings on 192.168.4.1/alarm
 */
void handleGetAlarm (AsyncWebServerRequest *request) {
  String stat;
  stat += "{\"alarmH\":" +        String(Prefrences.alarmH) + ",";
  stat += "\"alarmM\":" +         String(Prefrences.alarmM) + ",";
  stat += "\"isAlarm\":" +        String(Prefrences.isAlarm) + "}";
  request->send(200, "application/json", stat);
}

void handleGetColors (AsyncWebServerRequest *request) {
  String stat;
  stat += "{\"modeClock\":" +     String(Prefrences.modeClock) + ",";
  stat += "\"ffMode\":" +         String(Prefrences.ffMode) + ",";
  stat += "\"color60\":" +        String(Prefrences.color60) + ",";
  stat += "\"color24\":" +        String(Prefrences.color24) + ",";
  stat += "\"color12\":" +        String(Prefrences.color12) + ",";
  stat += "\"color12N\":" +       String(Prefrences.color12N) + ",";
  stat += "\"brightness\":" +     String(Prefrences.brightness) + "}";
  request->send(200, "application/json", stat);
}

void handlePostData(AsyncWebServerRequest *request){
  String message;
  bool found= false;
  
  if (request->hasParam("alarmH", true)) {
      message = request->getParam("alarmH", true)->value();
      Prefrences.alarmH = message.toInt();
      found = true;
  } 
  
  if (request->hasParam("alarmM", true)) {
      message = request->getParam("alarmM", true)->value();
      Prefrences.alarmM = message.toInt();
      found = true;
  }
  
  if (request->hasParam("isAlarm", true)) {
      message = request->getParam("isAlarm", true)->value();
      Prefrences.isAlarm = message.toInt();
      found = true;
  }
  
  if (request->hasParam("isShowClock", true)) {
      message = request->getParam("isShowClock", true)->value();
      Prefrences.isShowClock = message.toInt();
      found = true;
  }
  
  if (request->hasParam("isShowDate", true)) {
      message = request->getParam("isShowDate", true)->value();
      Prefrences.isShowDate = message.toInt();
      found = true;
  }
  
  if (request->hasParam("isShowBattery", true)) {
      message = request->getParam("isShowBattery", true)->value();
      Prefrences.isShowBattery = message.toInt();
      found = true;
  }
  
  if (request->hasParam("isShowRainbow", true)) {
      message = request->getParam("isShowRainbow", true)->value();
      Prefrences.isShowRainbow = message.toInt();
      found = true;
  }
  
  if (request->hasParam("isShowPackman", true)) {
      message = request->getParam("isShowPackman", true)->value();
      Prefrences.isShowPackman = message.toInt();
      found = true;
  }
  
  if (request->hasParam("modeClock", true)) {
      message = request->getParam("modeClock", true)->value();
      Prefrences.modeClock = message.toInt();
      found = true;
  }
  
  if (request->hasParam("color60", true)) {
      message = request->getParam("color60", true)->value();
      Prefrences.color60 = message.toInt();
      found = true;
  }
  
  if (request->hasParam("color24", true)) {
      message = request->getParam("color24", true)->value();
      Prefrences.color24 = message.toInt();
      found = true;
  }

  if (request->hasParam("color12N", true)) {
      message = request->getParam("color12N", true)->value();
      Prefrences.color12N = message.toInt();
      found = true;
  }

  if (request->hasParam("ffMode", true)) {
      message = request->getParam("ffMode", true)->value();
      Prefrences.ffMode = message.toInt();
      found = true;
  }
  
  if (request->hasParam("color12", true)) {
      message = request->getParam("color12", true)->value();
      Prefrences.color12 = message.toInt();
      found = true;
  }

  if (request->hasParam("brightness", true)) {
      message = request->getParam("brightness", true)->value();
      Prefrences.brightness = message.toInt();
      setBrightnessStrip();
      found = true;
  }

  if (request->hasParam("isJalali", true)) {
      message = request->getParam("isJalali", true)->value();
      Prefrences.isJalali = message.toInt();
      found = true;
  }

  if (request->hasParam("isTemprature", true)) {
      message = request->getParam("isTemprature", true)->value();
      Prefrences.isTemprature = message.toInt();
      found = true;
  }
  
  if (found)
    request->send(200, "text/plain", "OK");
  else
    request->send(400, "text/plain", "No Parameter Found");
}

void handleAdjustClock(AsyncWebServerRequest *request) {
  bool valid = true;
  uint8_t YYYY,MM,DD, hh,mm,ss; 
  if (valid &= request->hasParam("YYYY", true)) 
    YYYY = request->getParam("YYYY", true)->value().toInt();
  if (valid &= request->hasParam("MM", true)) 
    MM = request->getParam("MM", true)->value().toInt();
  if (valid &= request->hasParam("DD", true)) 
    DD = request->getParam("DD", true)->value().toInt();
  if (valid &= request->hasParam("hh", true)) 
    hh = request->getParam("hh", true)->value().toInt();
  if (valid &= request->hasParam("mm", true)) 
    mm = request->getParam("mm", true)->value().toInt();
  if (valid &= request->hasParam("ss", true)) 
    ss = request->getParam("ss", true)->value().toInt();

  if (valid) {
    request->send(200, "text/plain", "OK");
    adjustClock(YYYY, MM, DD, hh, mm, ss);
  } else
    request->send(400, "text/plain", "Some Parameters Missing");
}

void initServer() {
  WiFi.softAP(ssid, password);
  IPAddress IP = WiFi.softAPIP();
  Serial.print("AP IP address: ");
  Serial.println(IP); 
  
  server.on("/", HTTP_GET, [](AsyncWebServerRequest *request){
        request->send(200, "text/plain", "Sa@RoyAl Controller");
  });

  server.on("/ready", HTTP_GET, handleGetReady);
  server.on("/status", HTTP_GET, handleGetSatus);
  server.on("/setting", HTTP_GET, handleGetSetting);
  server.on("/alarm", HTTP_GET, handleGetAlarm);
  server.on("/colors", HTTP_GET, handleGetColors);
  
  // parameters are in the name of the Prefrences structure
  server.on("/post", HTTP_POST, handlePostData);

  server.on("/operate", [](AsyncWebServerRequest *request){
        isTriggered = true;
        request->send(200, "text/plain", "OK");
  });

  server.on("/adjust", HTTP_POST, handleAdjustClock);
  server.onNotFound(notFound);

  server.begin();
}

void setup() 
{
  Serial.begin(115200);
#ifndef ESP8266
  while (!Serial); // wait for serial port to connect. Needed for native USB
#endif

  initRTC();
  initTEMP();
  initStrip();
  turnOff();
  initServer();
}

void loop() 
{ 
  operate();
}

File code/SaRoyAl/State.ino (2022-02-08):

// States
#define S_CLOCK_INIT 0
#define S_CLOCK      1
#define S_DATE_INIT  2
#define S_DATE       3
#define S_BATRY_INIT 4
#define S_BATRY      5
#define S_RAINB_INIT 6
#define S_RAINB      7
#define S_PACKM_INIT 8
#define S_PACKM      9
#define S_TEMP_INIT  10
#define S_TEMP       11
#define S_IDLE       12
  
void goNextState() {
  switch(state) {
    case S_CLOCK_INIT : if(Prefrences.isShowClock)    {state = S_CLOCK; break;}
    case S_CLOCK      : if(Prefrences.isShowDate)     {state = S_DATE_INIT; break;}
    case S_DATE_INIT  : if(Prefrences.isShowDate)     {state = S_DATE; break;}
    case S_DATE       : if(Prefrences.isShowBattery)  {state = S_BATRY_INIT; break;}
    case S_BATRY_INIT : if(Prefrences.isShowBattery)  {state = S_BATRY; break;}
    case S_BATRY      : if(Prefrences.isTemprature)   {state = S_TEMP_INIT; break;}
    case S_TEMP_INIT  : if(Prefrences.isTemprature)   {state = S_TEMP; break;}
    case S_TEMP       : if(Prefrences.isShowRainbow)  {state = S_RAINB_INIT; break;}
    case S_RAINB_INIT : if(Prefrences.isShowRainbow)  {state = S_RAINB; break;}
    case S_RAINB      : if(Prefrences.isShowPackman)  {state = S_PACKM_INIT; break;}
    case S_PACKM_INIT : if(Prefrences.isShowPackman)  {state = S_PACKM; break;}
    case S_PACKM      : state = S_IDLE; break;
    default:
      state = S_CLOCK_INIT; break;
  }
}


void operate() {
  if (shouldLog) {
    log_temprature = getTemprature();
    log_battery = getBatteryPercentage();
    shouldLog = false;
  }
  // if we are not trigered and clock is not showing
  // capture clap
  if(!isTriggered && !isOperating){
    checkTriger();
  } else if (isTriggered){
    // else if we are trigered call the operation once
    // operation should     
    isTriggered = false;
    isOperating = true;
    // Show data once, next calls should be done by timer
    lastCheckpoint = millis();
    threshold = 200;
    state = 0;
  } else if (isOperating) {
    if (millis() - lastCheckpoint >  threshold){
      lastCheckpoint = millis();
      handleStates();
    }
  }

  if (millis() - alarmCheck > 1000) {
    alarmCheck = millis();
    handleAlarm();
  }
}

void handleStates() {
  /*
   * case i, i+1 is for one state
   * state i is for initialization and state i+1 is for main loop
   * each state at the end of its operation make isDone 1 to show
   * the controller to go for the next state;
   */
  switch(state) {
    case S_TEMP_INIT  : updateTemprature();
    case S_RAINB_INIT :
    case S_BATRY_INIT : updateBatteryPercentage();
    case S_DATE_INIT  :
    case S_PACKM_INIT : 
    case S_CLOCK_INIT : turnOff(); i_loc = 0; j=0; k=1; goNextState(); startState = millis(); break;
    case S_CLOCK      : updateTime(); displayTime(); break;
    case S_DATE       : displayDate(); break;
    case S_BATRY      : displayPercentage(); break;
    case S_TEMP       : displayTemprature(); break;
    case S_RAINB      : displayRainbow(); break;
    case S_PACKM      : displayPackman(); break;
    case S_IDLE       : state = S_CLOCK_INIT; turnOff(); isOperating = false;
    default:
      state = S_CLOCK_INIT; break;
  }
}
